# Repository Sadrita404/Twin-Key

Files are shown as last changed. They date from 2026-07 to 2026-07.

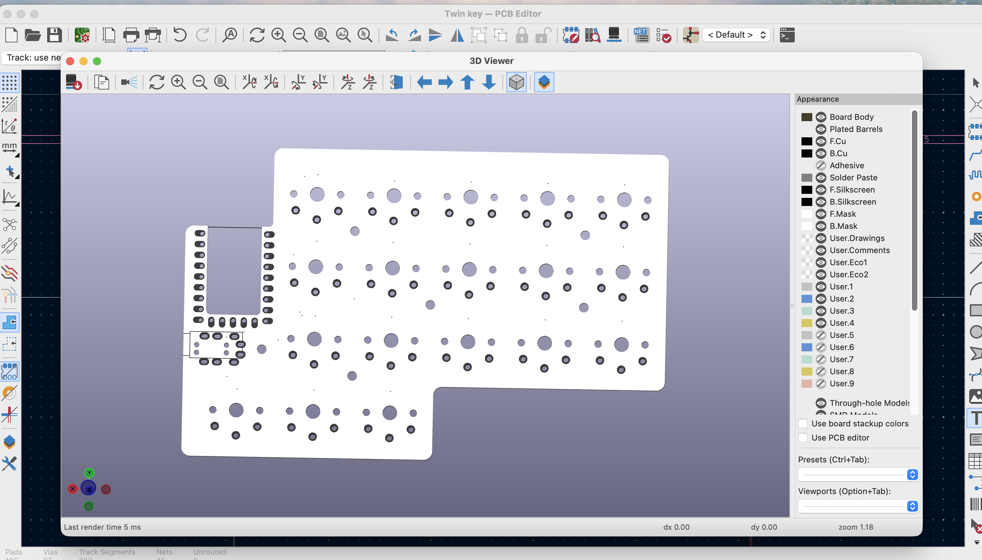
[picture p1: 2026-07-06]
Images/18.png

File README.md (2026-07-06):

<div align="center">
  <table border="0" cellpadding="0" cellspacing="0">
    <tr>
      <td align="center" style="background: #ffffff; border: 1px solid #d0d7de; border-radius: 12px; padding: 16px; box-shadow: 0 4px 12px rgba(0,0,0,0.05);">
        Rough Layout For The PCB
        <div style="margin-top: 12px; font-family: -apple-system, BlinkMacSystemFont, 'Segoe UI', Helvetica, Arial, sans-serif; font-size: 13px; color: #57606a; font-weight: 500;">
      </td>
    </tr>
  </table>
</div>

|Title | Twin Key |
|:-- |:--|
|Author | Sadrita Neogi|

# Website for Twin Key go check it out - [Live URL](https://twin-keyboard.vercel.app/)

### what I have built

This split keyboard is basically fixes everything annoying about standard typing. We took the logic of an ortholinear grid (where everything is predictable) and mashed it together with a column stagger that actually matches how long your fingers are. For me this type of form factor keyboard is good for long hours of typing.

### Why I choose this project?
So behind choosing this project is basically I love split keyboard and the way it just fold and compact. It is easy to carry and it is good for writing for long hours, so I wanted to make one for myself not to buy it but to make it for myself and customisable, so this is the reason I choose this project.

### what I have learned

Through out making this project I have learned a lot of thing but the main that I gain strengh is listed below 

* PCB design using KiCad
* Mechanical keyboard architecture
* KMK scripting
* Fusion 360 CAD Work 
* How to choose Part's for project in budget

### Features 

* It's an 18 - 18 layout Split Keyboard .
* The connection between two keyboard are using 3.5mm TRRS to TRRS Cable.
* The main micro controller of this keyboard is RP2040-Zero and RP2040-Tiny.
* The PCB of this keyboard is reversible so that we can reduce the PCB wastage.
* This is an wired Keyboard 
* This Keyboard is made for good ergonomic
* QMK Firmware support for this keyboard 
* Hot-swappable ( for every keys )
* This is a low profile keyboard 
* Custom 3d printed case and top plate

### Components Used in this Build 

| Item |
| --- |
| PCB (MOQ 5) |
| RP2040-Zero (left side) |
| RP2040-Tiny (right side) |
| Kailh Choc v2 Low Profile Switches |
| Kailh Choc PG1350 Hot Swap Sockets |
| CFX MX Low Profile Keycaps |
| 1N4148 SOD-123 SMD Diode |
| PJ-320A TRRS Jack |
| M2×3 heat-set threaded inserts |
| M2×5 countersunk screws |
| 3.5mm TRRS to TRRS cable |
| Type-C to Type-C cable |

## Firmware

Precompiled VIA-enabled firmware:

- Flash `twin_key_sadrita.uf2` under [Firmware/](Firmware/) to the RP2040 MCUs.
- Load the [via.json](https://github.com/Sadrita404/Twin-Key/blob/main/Firmware/QMK/keyboards/twin_key/via.json) file in `Design` tab for [VIA](https://usevia.app) configuration.

QMK source is available under [firmware/QMK/keyboards/Twin-Key](https://github.com/Sadrita404/Twin-Key/tree/main/Firmware/QMK/keyboards/twin_key).

### Journal - [Journal.md](https://github.com/Sadrita404/Twin-Key/blob/main/Journal.md)

<div align="center">

| | Building Process | |
| :---: | :---: | :---: |
|  |  |  |
|  |  |  |
|  |  |  |
|  |  |  |
|  |  |  |
|  |  |  |
|  |  |  |
|  |  |  |

<div align="center">
  <h2> Final PCB </h2>
  <table border="0" cellpadding="10" cellspacing="0" style="border-collapse: collapse;">
    <tr>
      <!-- FRONT SIDE CARD -->
      <td align="center" valign="top" width="50%" style="background: #ffffff; border: 1px solid #d0d7de; border-radius: 12px; padding: 16px; box-shadow: 0 4px 12px rgba(0,0,0,0.05);">
        Front Side View
        <div style="margin-top: 12px; font-family: -apple-system, BlinkMacSystemFont, 'Segoe UI', Helvetica, Arial, sans-serif; font-size: 13px; color: #57606a; font-weight: 600; text-transform: uppercase; letter-spacing: 0.5px;">
          ▲ Left Side
        </div>
      </td>
      <!-- SPACER FOR GITHUB MOBILE DEGRADATION -->
      <td width="2%">&nbsp;</td>
      <!-- BACK SIDE CARD -->
      <td align="center" valign="top" width="50%" style="background: #ffffff; border: 1px solid #d0d7de; border-radius: 12px; padding: 16px; box-shadow: 0 4px 12px rgba(0,0,0,0.05);">
        Back Side View
        <div style="margin-top: 12px; font-family: -apple-system, BlinkMacSystemFont, 'Segoe UI', Helvetica, Arial, sans-serif; font-size: 13px; color: #57606a; font-weight: 600; text-transform: uppercase; letter-spacing: 0.5px;">
          ▲ Right Side 
        </div>
      </td>
    </tr>
  </table>
</div>
</div>

## Final Render 

<div align="center">

render 1

render 2

render 3

</div>

<div align="center">
  <h2> Bill of Materials </h2>
</div>

| Component Name | Purpose | Qty | Unit Price | Total Price | Source Link |
| :--- | :--- | :---: | :---: | :---: | :---: |
| **PCB (moq5)** | The Main Board | 5 | $1.54 | $7.70 | [JLC PCB](https://jlcpcb.com/) |
| **RP2040-Zero (left side)** | Micro Controller | 1 | $4.43 | $4.43 | [Robu](https://robu.in/product/waveshare-rp2040-zero-without-header/) |
| **RP2040-Tiny (right side)** | Micro Controller | 1 | $6.26 | $6.26 | [Robu](https://robu.in/product/waveshare-rp2350-tiny-development-board-based-on-rp2350a-dual-core-dual-architecture-microcontroller/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) |
| **Kailh Choc v2 Low Profile Switches** | The switches to press | 40 | $0.63 | $25.00 | [Neomacro](https://neomacro.in/products/kailh-choc-v2-low-profile-switches?variant=51316563345686) |
| **Kailh Choc PG1350 Hot Swap Sockets** | To put the switches | 40 | $0.18 | $7.00 | [Neomacro](https://neomacro.in/products/kailh-choc-pg1350-hot-swap-sockets) |
| **CFX MX Low Profile Keycaps** | For the Switches | 1 | $26.30 | $26.30 | [Neomacro](https://neomacro.in/products/cfx-mx-low-profile-keycaps) |
| **1N4148 SOD-123 SMD Diode** | For the PCB Board | 40 | $0.03 | $1.00 | [Stackskb](https://stackskb.com/store/1n4148-sod-123-smd-diode/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) |
| **PJ-320A TRRS Jack** | For the Wire Connection | 2 | $0.50 | $1.00 | [Stackskb](https://stackskb.com/store/pj-320a-jack/) |
| **M2×3 heat-set threaded inserts** | For fixing the case | 20 | $0.02 | $0.40 | [Self Sourced](https://onlyscrews.in/products/m2-x-3mm-brass-threaded-inserts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) |
| **M2×5 countersunk screws** | For fixing the case | 20 | $0.03 | $0.60 | [Self Sourced](https://onlyscrews.in/products/m2-5-x-16mm-phillips-csk-ss-304-screw-dia-2-5mm-length-16mm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{adgroup}&gad_source=1&gad_campaignid=23953886635&gbraid=0AAAAA9sP2STwTW01fCxMnAJNjH3poMXxs&gclid=CjwKCAjwpK3SBhASEiwAtV1SPAjy69mRkSBp_vrUqPKL9_t7nT_D9hi1XdFlchSsnUIymW6eQlEjZhoCIz4QAvD_BwE) |
| **3.5mm TRRS to TRRS Cable** | For the keyboard connection | 1 | $4.80 | $4.80 | [Amazon](https://www.amazon.in/IVON-3-5mm-Cable-Microphone-Compatible/dp/B0G2BPJMXV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) |
| **Type C to Type C Cable** | For the micro controller | 1 | $2.00 | $2.00 | [Amazon](https://www.amazon.in/HAMMER-Braided-Chraging-Compatible-Enabled/dp/B0CXM7FCHC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) |
| **3D Print** | For the Case | 1 | $0.00 | $0.00 | [#printing-legion](https://printlegion.hackclub.com/) |
| **Shipping** | Including PCB shipping | - | - | $13.40 | - |
| **Total** | | | | **$99.89** | |
| **Round Off Budget** | | | | **$100** | |

I have provided the links for the parts I will be self-sourcing, so that if readers want to recreate this, they will be able to get all the parts.This is also updated on the [bom.csv](/bom.csv)

## Copyright and License
Copyright (c) 2026 Sadrita Neogi. All rights reserved.

All files are licensed under the MIT license. For more information, see the [LICENSE](LICENSE).

Project Under Hack Club

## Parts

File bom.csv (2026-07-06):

Name | Purpose | Quantity | Total Cost (USD) | Link | Distributor
PCB(moq5) | The Main Board | 5 | 7.70 | https://jlcpcb.com/ | JLC PCB
RP2040-Zero (left side) | Micro Controller | 1 | 4.43 | https://robu.in/product/waveshare-rp2040-zero-without-header/ | Robu
RP2040-Tiny (right side) | Micro Controller | 1 | 6.26 | https://robu.in/product/waveshare-rp2350-tiny-development-board-based-on-rp2350a-dual-core-dual-architecture-microcontroller/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 | Robu
Kailh Choc v2 Low Profile Switches | The switches to press | 40 | 25 | https://neomacro.in/products/kailh-choc-v2-low-profile-switches?variant=51316563345686 | Neomacro
Kailh Choc PG1350 Hot Swap Sockets | To put the switches | 40 | 7 | https://neomacro.in/products/kailh-choc-pg1350-hot-swap-sockets | Neomacro
CFX MX Low Profile Keycaps | For the Switches | 1 | 26.3 | https://neomacro.in/products/cfx-mx-low-profile-keycaps | Neomacro
1N4148 SOD-123 SMD Diode | For the PCB Board | 40 | 1 | https://stackskb.com/store/1n4148-sod-123-smd-diode/ | Stackskb
PJ-320A TRRS Jack | For the Wire Connection | 2 | 1 | https://stackskb.com/store/pj-320a-jack/ | Stackskb
M2×3 heat-set threaded inserts | For fixing the case | 20 | 0.4 | https://onlyscrews.in/products/m2-x-3mm-brass-threaded-inserts | Onlyscrews
M2×5 countersunk screws | For fixing the case | 20 | 0.6 | https://onlyscrews.in/products/m2-5-x-16mm-phillips-csk-ss-304-screw-dia-2-5mm-length-16mm?currency=INR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 | Onlyscrews
3.5mm TRRS to TRRS | For the keyboard connection | 1 | 4.8 | https://www.amazon.in/IVON-3-5mm-Cable-Microphone-Compatible/dp/B0G2BPJMXV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 | Amazon
type c to type c cable | For the micro controller | 1 | 2 | https://www.amazon.in/HAMMER-Braided-Chraging-Compatible-Enabled/dp/B0CXM7FCHC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 | Amazon
3d Print | For the Case | 1 | 0 | https://printlegion.hackclub.com/ | #printing-legion
Shipping | including PCB shipping |  | 13.40
Total |  |  | 99.89
Round Off Budget |  |  | 100

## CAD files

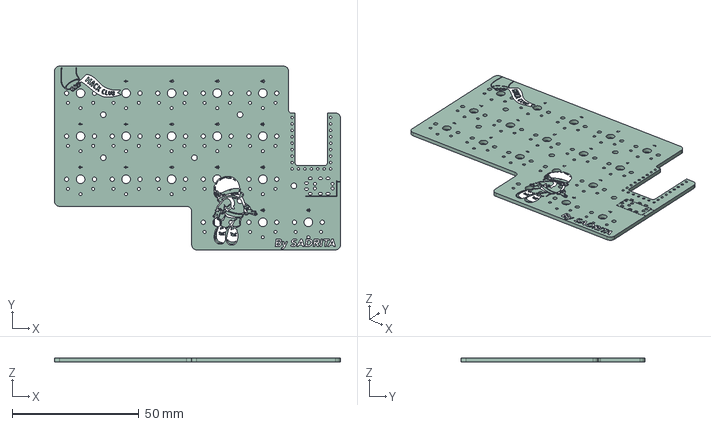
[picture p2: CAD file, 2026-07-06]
CAD/pcb.step
113.0 x 72.6 x 1.66 mm
Twin key_silkscreen x 2
Twin key_PCB

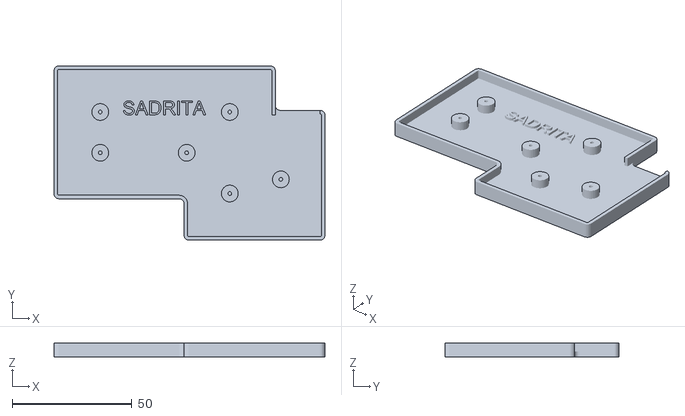
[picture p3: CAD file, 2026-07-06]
STL/Left Case.stl
113.0 x 72.6 x 6.00

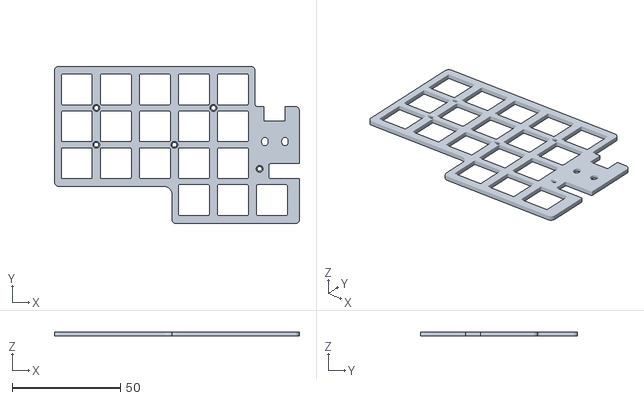
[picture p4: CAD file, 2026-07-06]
STL/plate-left.stl
113.0 x 72.6 x 2.00

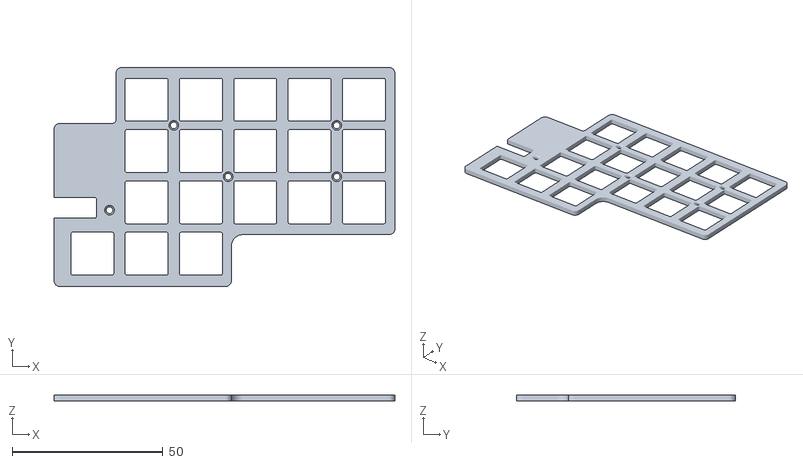
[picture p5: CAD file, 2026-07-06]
STL/plate-right.stl
113.0 x 72.6 x 2.00

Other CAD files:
STL/Right Case.stl

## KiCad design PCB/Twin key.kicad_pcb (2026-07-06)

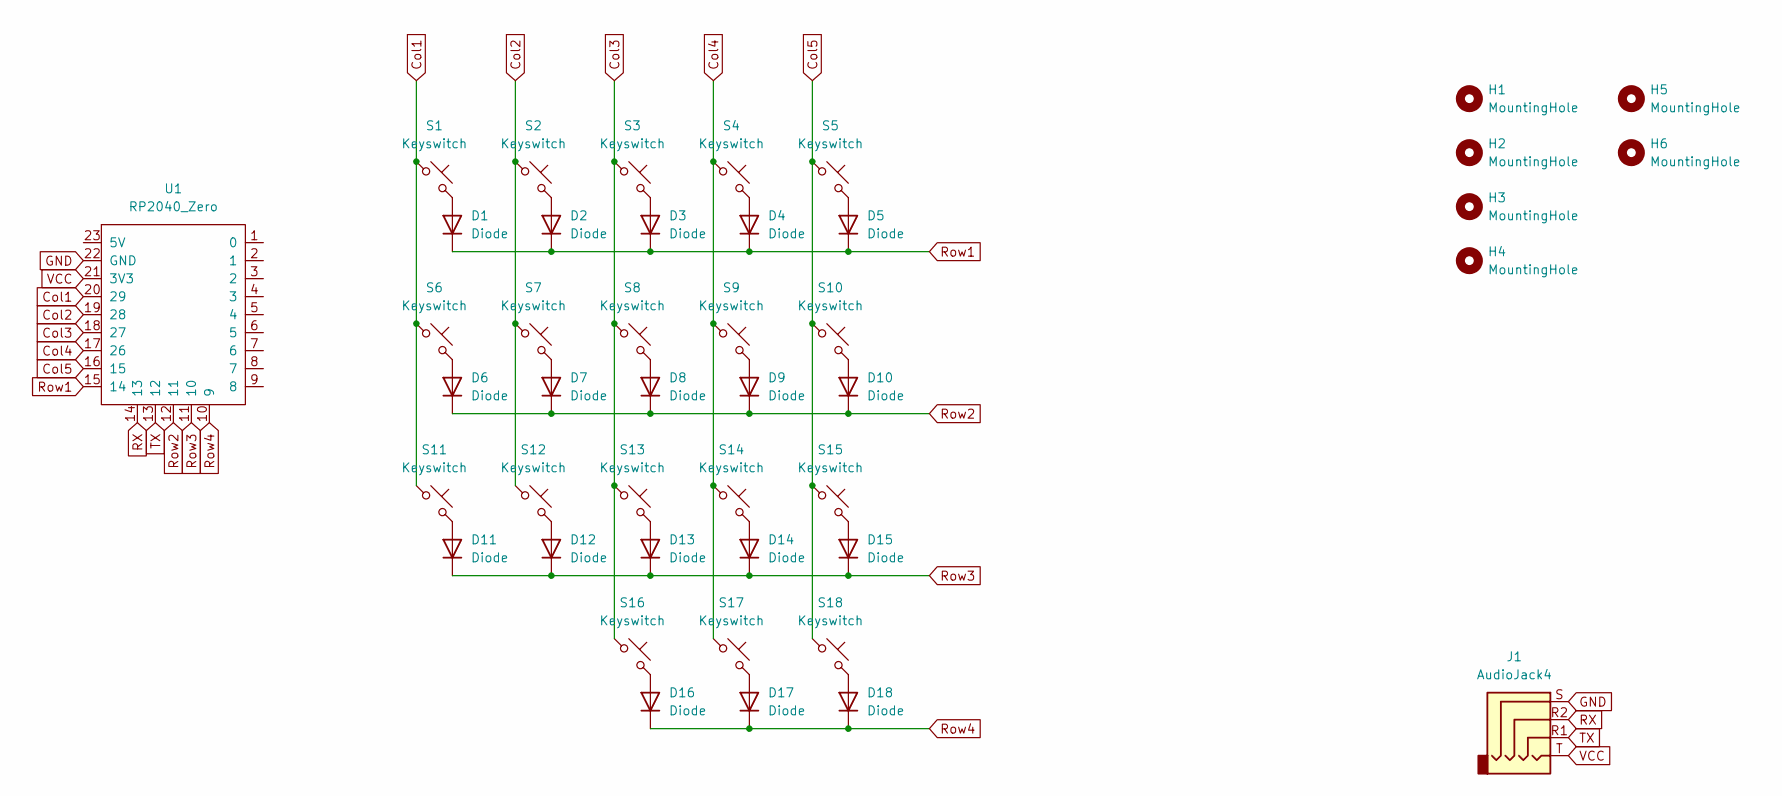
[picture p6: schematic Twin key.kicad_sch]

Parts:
D1, D2, D3, D4, D5, D6, D7, D8, D9, D10, D11, D12, D13, D14, D15, D16, D17, D18: Diode; Diode_SOD-123
H1, H2, H3, H4, H5, H6: MountingHole; MountingHole_2.2mm_M2
J1: AudioJack4; CON_MJ-4PP-9_Reversible
S1, S2, S3, S4, S5, S6, S7, S8, S9, S10, S11, S12, S13, S14, S15, S16, S17, S18: Keyswitch; SW_choc_Reversible_1u
U1: RP2040_Zero

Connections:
Col1: S1.1, S6.1, S11.1, U1.20 (29)
Col2: S2.1, S7.1, S12.1, U1.19 (28)
Col3: S3.1, S8.1, S13.1, S16.1, U1.18 (27)
Col4: S4.1, S9.1, S14.1, S17.1, U1.17 (26)
Col5: S5.1, S10.1, S15.1, S18.1, U1.16 (15)
GND: J1.S, U1.22 (GND)
unnamed: D1.2 (A), S1.2
unnamed: D2.2 (A), S2.2
unnamed: D3.2 (A), S3.2
unnamed: D4.2 (A), S4.2
unnamed: D5.2 (A), S5.2
unnamed: D6.2 (A), S6.2
unnamed: D7.2 (A), S7.2
unnamed: D8.2 (A), S8.2
unnamed: D9.2 (A), S9.2
unnamed: D10.2 (A), S10.2
unnamed: D11.2 (A), S11.2
unnamed: D12.2 (A), S12.2
unnamed: D13.2 (A), S13.2
unnamed: D14.2 (A), S14.2
unnamed: D15.2 (A), S15.2
unnamed: D16.2 (A), S16.2
unnamed: D17.2 (A), S17.2
unnamed: D18.2 (A), S18.2
RX: J1.R2, U1.14 (13)
Row1: D1.1 (K), D2.1 (K), D3.1 (K), D4.1 (K), D5.1 (K), U1.15 (14)
Row2: D6.1 (K), D7.1 (K), D8.1 (K), D9.1 (K), D10.1 (K), U1.12 (11)
Row3: D11.1 (K), D12.1 (K), D13.1 (K), D14.1 (K), D15.1 (K), U1.11 (10)
Row4: D16.1 (K), D17.1 (K), D18.1 (K), U1.10 (9)
TX: J1.R1, U1.13 (12)
VCC: J1.T, U1.21 (3V3)

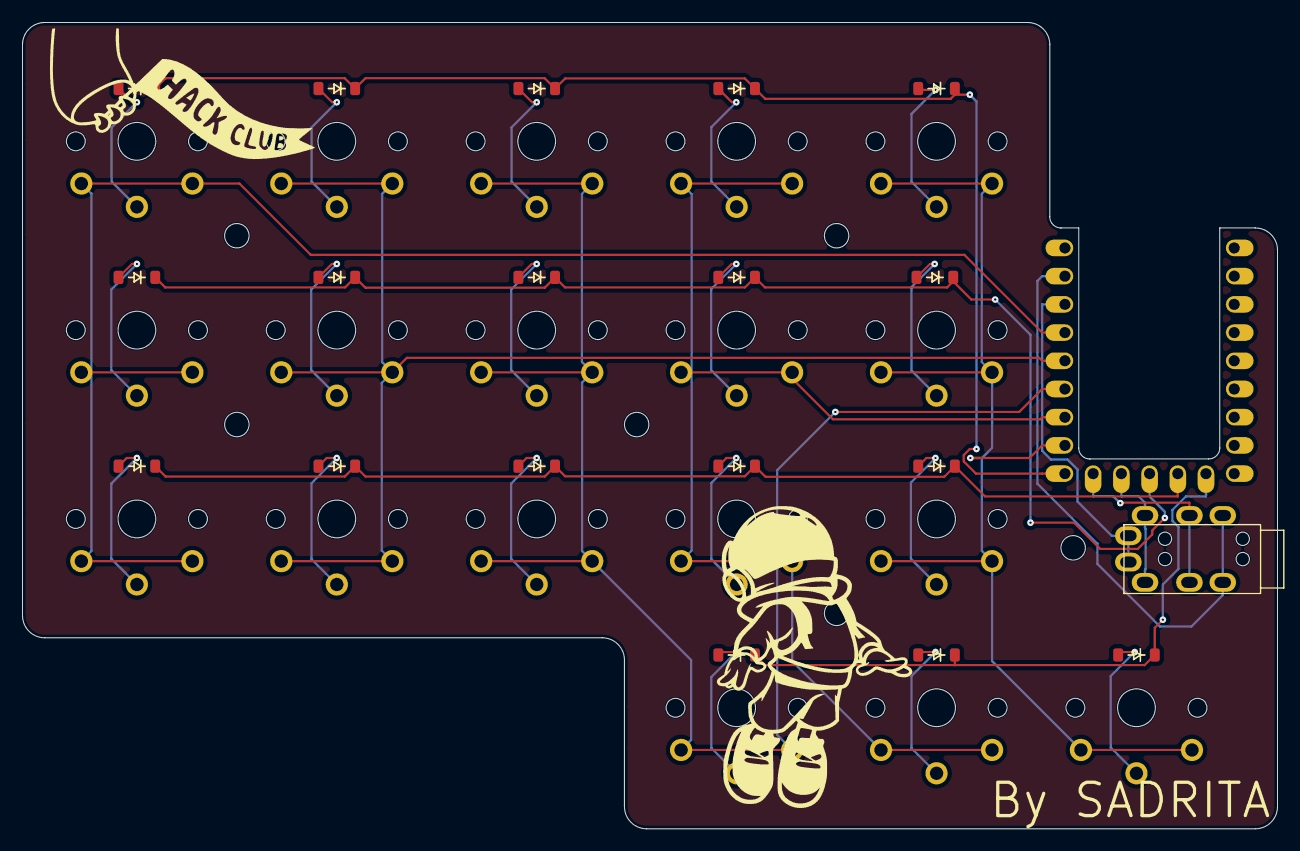
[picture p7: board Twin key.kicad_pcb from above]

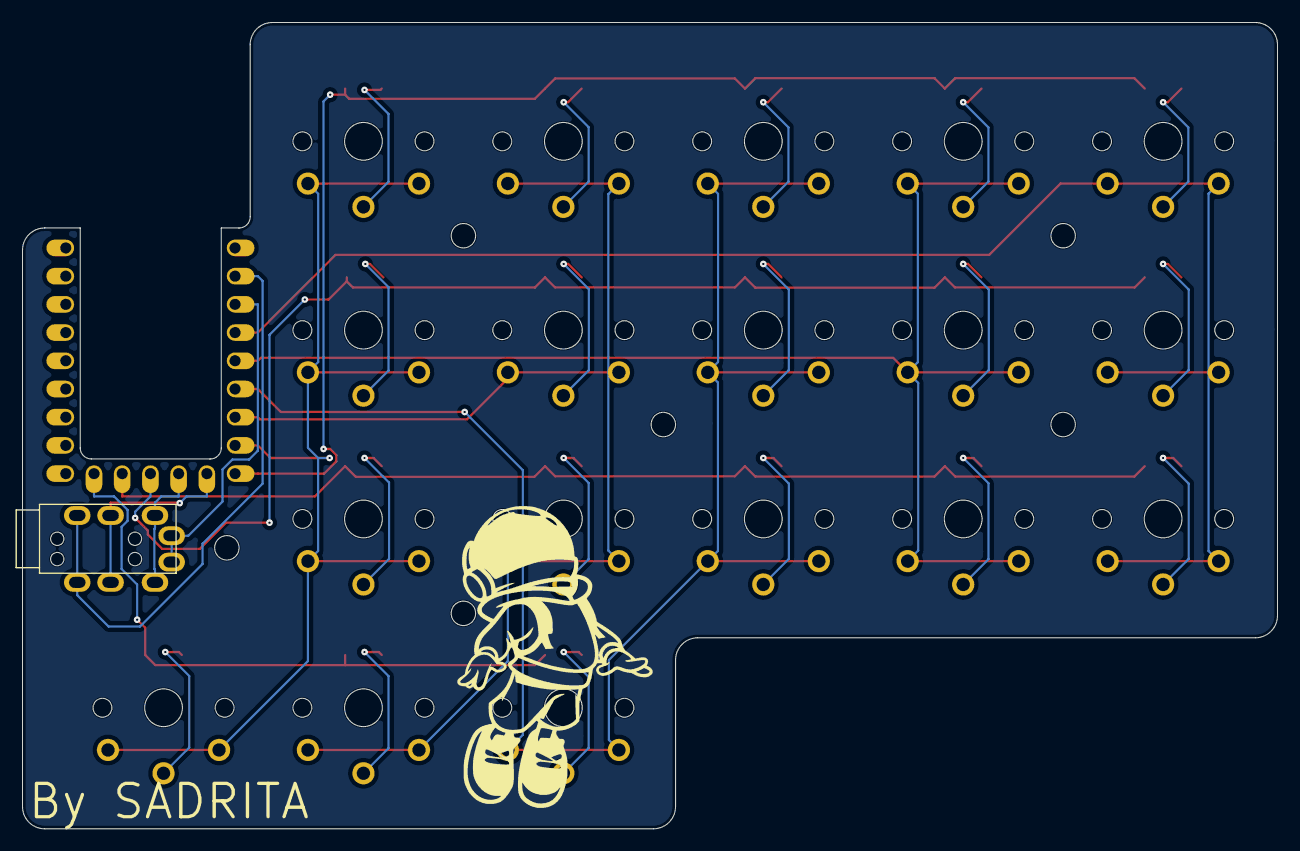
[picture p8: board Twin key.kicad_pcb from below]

Board: 2 copper layers, 113.0 x 72.6 mm, 44 parts (19 on the bottom side), 31 nets.

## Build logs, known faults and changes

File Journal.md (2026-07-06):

| Title | Twin Key |
| :-- | :---|
|Author |Sadrita Neogi|
|Type | Split Keyboard |
Total Hrs | 20.5 |

## June 24th : Research about the micro controller for the keyboard

Today I went in Google and search about the different kind of micro controller that I can use in the split keyboard that is cheap and easily available. Also, that can be easily programmable, and everyone can recreate this.





Screenshot 2026-07-06 at 11 10 08 AM

Screenshot 2026-07-06 at 11 11 10 AM

I am following this doc - https://files.seeedstudio.com/wiki/XIAO-RP2040/res/rp2040_datasheet.pdf
https://www.waveshare.com/wiki/RP2040-Zero?srsltid=AfmBOorqaLMlEx-NeF0sFeqP3B-EAvL2AJbcMyj2hVzvlR0YcNgk93x1

this are the two doc from where I know about the micro contoller 







So after reading through all of the data sheet and the pin out for each of the micro controller since it would be an split keyboard, so I doesn't need maximum number of pin out point like **raspberry pi pico** so for that reason to make it  cost-effective, I am going with **RP2040-Zero** micro controller and **RP2040-Tiny**
And the type of keyboard that I am building for that, I think it should be enough to give the power distribution, and also it can be easily done with the key mapping features

#### Now the keyboard layout 





I have also went online to see the types of the split keyboard layout that are widely used , but I want to be make one custom for me , I will try to design my own ..

**Total Time Spent - 2.4hr**

---

## June 26th : Started with the schematic of the PCB

So in the previous day, I have already selected the micro controller and pretty much about the layout of the keyboard. So today I will going to make the schematic for the PCB so that I can start working on the PCB board and I can start working on rest of the thing that can be done only after making the schematic because schematic is the first part for making any PCB and for me taking the right footprint from the library with matching it to the data sheet will take me a lot of time, and I finally managed to get all of this.

**RP2040-Zero**



**PJ-320A TRRS Jack**



**All the Keysss..**



#### So during researching about the keyboard, I found out an crucial problem like when we general make split keyboard, we make two PCB for each of the side one for left side and one for right side and when we order the PCB we get five, which is the minimum order quantity but I think that is kind of a wastage when we don't really use the rest of the PCB, so the layout that I will be working on is quite interesting . We will get the five PCBs and we can use each of the PCBs for left and right side by turning it upside down like it can it was working like a reversible PCB so we can use any PCB for left or right hand side, so by this we can reduce the wastage of the PCB. Also, it will easy to make the case and the PCB like I need to just work only for one of the PCBs and I can get it fabricated and I can use it for the both sides, so that's my plan.

## Inspo
Screenshot 2026-07-06 at 9 58 13 AM

Screenshot 2026-07-06 at 9 59 05 AM

**Final Schematic**



**Total Time Spent - 3.5hr**

---

## June 28th : Done With the PCB tracing 

So previously I have completed a schematic of the PCB and I take one day gap because I was not in my hometown, so after coming I went to look at the schematic, and then I realise that I need to do a lot of work like I have just made the schematic now I need to import that schematic into PCB designing. Then I need to trace all the pads. So today I will do all of that hopefully completed that, like the main problem is the DRC check error,  I don't know. I have done completing all the traces, but suddenly it's showing error. Hopefully, I will try my best this time. I will do it with all my concentration so that nothing gets out and all the pads should be routed.

**updating PCB from schematic**











Finally, after a lot of time, I have finally completed the PCB designing part steal the PCB looks bit more like normal. I need to add some silk screen to the PCV, I will do it on the next day because today, I am so tired doing all the PCB tracing, and the copper layer is too much

**all pads are routed**



**Total Time Spent - 4.6hr**

---

## July 2nd : Completing the rest of the PCB part

So today I started making the pcb more good looking by adding the silk screen into the pcb and I have export the PCB step file for the case design that I need to make for this PCb .
I make the PCB silk screen simple because when I will solder all the parts like the switches all this will not be visible to use so I think I think it will be better to make the PCB clean 

**adding my name to the PCB**







**Hack Club Logo added to the PCB**





#### DRC Check - yaa No error after tracing all the pads correctly 





**Final look**

#### Left 



#### Right 



**plotting the Garber file**



**Total Time Spent - 2hr**

---

## July 3rd : Working on some errors 

So I have added one extra rows in the keyboard schematic so that I can reduece the Macro layer in the firmware and I have more room to add the key mapping in the first layer to add the basic needs of an keyboard ..

Screenshot 2026-07-06 at 11 00 37 AM

Next I went to the JLC pcb to just check what will be the cost of my PCB after production 

**Also I have generate the gerber file again with this changes**

bill 1

For today I will not do any work as I need to do my school work now and suddenly I thought to add one extra row in the keyboard so that's whay I am just making this amout of progress today hopefully, done something based in the coming days..

**Total Time Spent - 0.5hr**

---

## July 5th : Working on Keyboard Case (CAD)
Today I first took the measurement of the PCB from the PCB designing software and noted down then I move to fusion 360 where I mostly design all of the CAD model for my projects and I went there. I design and simple elegant kiss for that which took me a lot of time and iteration so that it can fit perfectly and I also export the PCB step file. and use it to the CAD model also I have added keycaps to the keyboard which is pretty good to see.

Screenshot 2026-07-07 at 2 06 34 AM

Screenshot 2026-07-07 at 2 07 07 AM

Screenshot 2026-07-07 at 2 06 59 AM

Screenshot 2026-07-07 at 2 06 52 AM

















**Now I move to add the keycaps in the model to make the final assemble file**



















**Total Time Spent - 3.1hr**

---

## July 6th : Working on the Right Side of the Keyboard (CAD)

So today I started woriking on the right side of the keyboard mostly I will be adding all the keycaps and render some good images for the github . This took me a lot of time as I have no experience in the field of Rendering and creating environment scene in fusion 360 . But you did making this project. I have learn how to do the simple one, and I have also enhanced my CAD skill by pretty Much about what I know earlier.

















#### Now rendering images in fusion 360







### FInal Output 

render 1

render 2

render 3

**Total Time Spent - 3.3hr**

---

## July 7th : Making the BOM for this project 

This is one of the last crucial part of every project, so this is the time when I created the budget of the keyboard. In earlier, I have created an rough bill of material, but this is the final. I need to go through all the components and parts again, and then I can make the final bill of material.

bill 1

Screenshot 2026-07-07 at 12 53 02 AM

Screenshot 2026-07-07 at 12 53 13 AM

Screenshot 2026-07-07 at 12 53 24 AM

Screenshot 2026-07-07 at 12 53 35 AM

Screenshot 2026-07-07 at 12 53 51 AM

Screenshot 2026-07-07 at 12 54 34 AM

Screenshot 2026-07-07 at 12 51 01 AM

**Total Time Spent - 1.1hr**

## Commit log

2026-07-06 Update fmt.Println message from 'Hello' to 'Goodbye'
2026-07-06 case stl added
    [Left Case.stl, Right Case.stl]
2026-07-06 top plate added
    [plate-right.stl]
